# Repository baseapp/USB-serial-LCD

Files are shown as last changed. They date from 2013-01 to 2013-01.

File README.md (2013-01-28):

BaseApp USB-serial LCD/Keypad
-----------------------------

Supports HD44780 compatible LCDs(in 4-bit mode). Enumerates as a serial com port, and can be
used with software like LCD smartie for windows, or LCDproc etc. for
linux using matrixorbital commands. Also supports upto 4x4 matrix keypad.

List of supported matrix orbital commands supported is in MatrixOrbital.h

Code is based on http://dangerousprototypes.com/docs/USB_Universal_LCD_backpack

- This code is for PIC18F25K50, and can me modified easily for 18f45k50,
  both do not require external crystal for USB.
- No bootloader
- Keypad press/release output on serial

- Compiler - tested with mplabc18 v3.44
- Requires USB stack from microchip applications library

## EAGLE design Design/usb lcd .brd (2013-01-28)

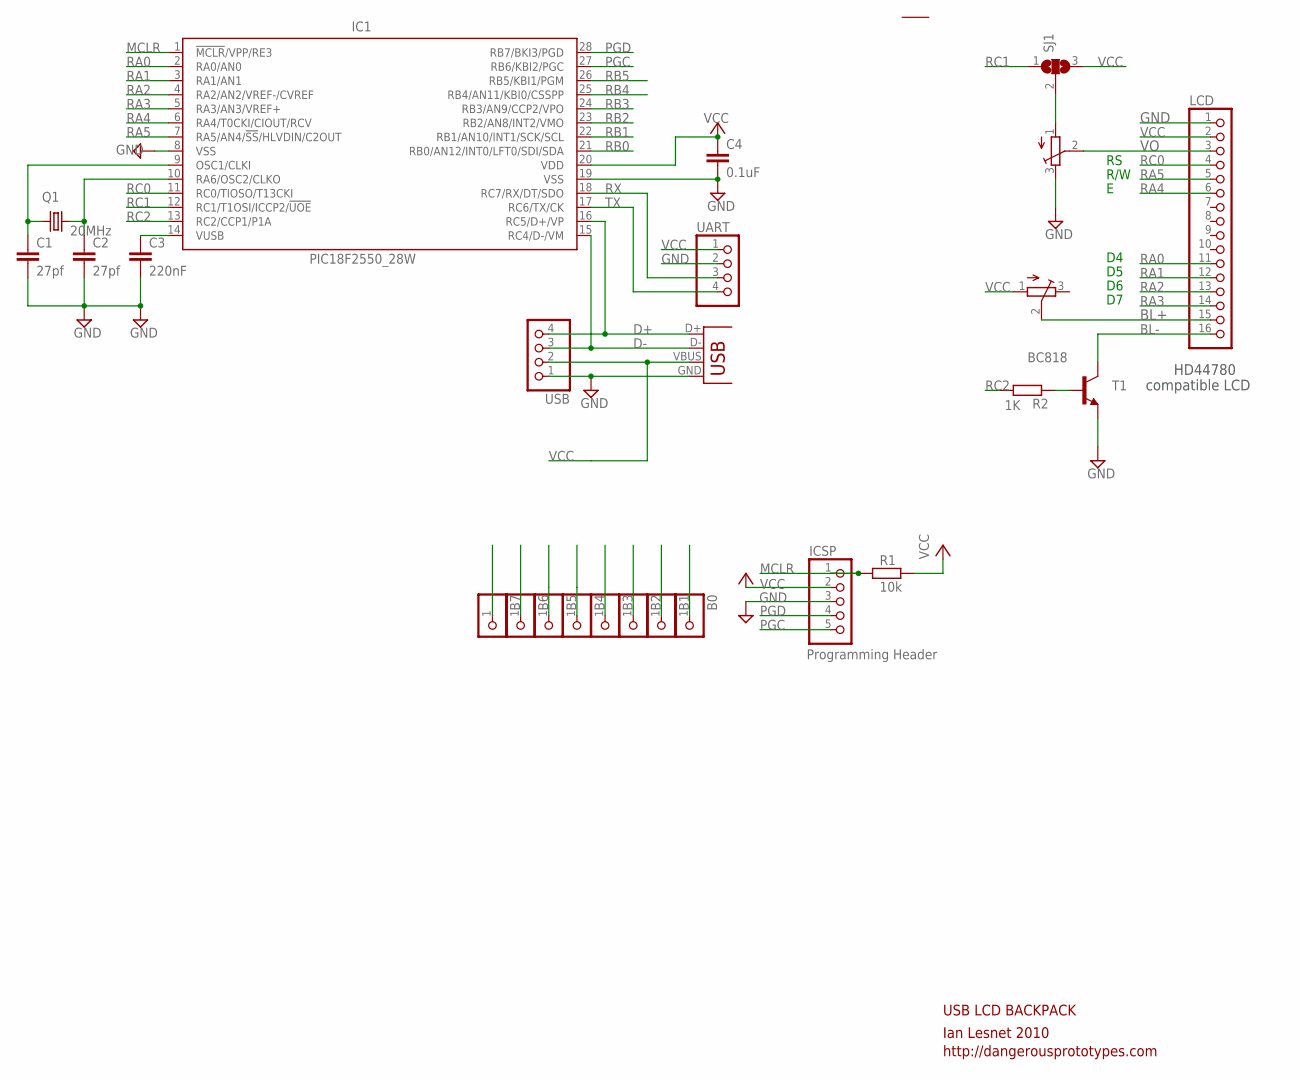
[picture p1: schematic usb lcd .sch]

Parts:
B0, B1, B2, B3, B4, B5, B6, B7: PINHD-1X1; 1X01
C1, C2: 27pf; C0805
C3: 220nF; C0805
C4: 0.1uF; C0805
IC1: PIC18F2550_28W; SO28W
ICSP: PINHD-1X5; 1X05
J1: USBSMD; USB-MINIB
LCD: PINHD-1X16; 1X16
Q1: 20MHz; HC49UP
R1: 10k; R0805
R2: 1K; M0805
SJ1: SJ2W; SJ_2
T1: BC818; SOT23-BEC
U$3, U$4: 3MM_TRIMPOT
UART: PINHD-1X4; 1X04
USB: PINHD-1X4; 1X04

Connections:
BASE: R2.1, T1.B
BL+: LCD.15, U$4.2 (S)
BL-: LCD.16, T1.C
D+: IC1.16 (RC5/D+/VP), J1.D+, USB.4
D-: IC1.15 (RC4/D-/VM), J1.D-, USB.3
GND: C1.2, C2.2, C3.2, C4.2, IC1.8 (VSS), IC1.19 (VSS), ICSP.3, J1.GND, LCD.1, T1.E, U$3.3 (E), UART.2, USB.1
MCLR: IC1.1 (!MCLR!/VPP/RE3), ICSP.1, R1.1
unnamed: SJ1.2, U$3.1 (A)
unnamed: C2.1, IC1.10 (RA6/OSC2/CLKO), Q1.2
unnamed: C1.1, IC1.9 (OSC1/CLKI), Q1.1
unnamed: C3.1, IC1.14 (VUSB)
PGC: B6.1, IC1.27 (RB6/KBI2/PGC), ICSP.5
PGD: B7.1, IC1.28 (RB7/BKI3/PGD), ICSP.4
RA0: IC1.2 (RA0/AN0), LCD.11
RA1: IC1.3 (RA1/AN1), LCD.12
RA2: IC1.4 (RA2/AN2/VREF-/CVREF), LCD.13
RA3: IC1.5 (RA3/AN3/VREF+), LCD.14
RA4: IC1.6 (RA4/T0CKI/CIOUT/RCV), LCD.6
RA5: IC1.7 (RA5/AN4/!SS!/HLVDIN/C2OUT), LCD.5
RB0: B0.1, IC1.21 (RB0/AN12/INT0/LFT0/SDI/SDA)
RB1: B1.1, IC1.22 (RB1/AN10/INT1/SCK/SCL)
RB2: B2.1, IC1.23 (RB2/AN8/INT2/VMO)
RB3: B3.1, IC1.24 (RB3/AN9/CCP2/VPO)
RB4: B4.1, IC1.25 (RB4/AN11/KBI0/CSSPP)
RB5: B5.1, IC1.26 (RB5/KBI1/PGM)
RC0: IC1.11 (RC0/TIOSO/T13CKI), LCD.4
RC1: IC1.12 (RC1/T1OSI/ICCP2/!UOE), SJ1.1
RC2: IC1.13 (RC2/CCP1/P1A), R2.2
RX: IC1.18 (RC7/RX/DT/SDO), UART.3
TX: IC1.17 (RC6/TX/CK), UART.4
VCC: C4.1, IC1.20 (VDD), ICSP.2, J1.VBUS, LCD.2, R1.2, SJ1.3, U$4.1 (A), UART.1, USB.2
VO: LCD.3, U$3.2 (S)

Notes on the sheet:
USB LCD BACKPACK
Ian Lesnet 2010
http://dangerousprototypes.com
HD44780
compatible LCD
R/W
Programming Header

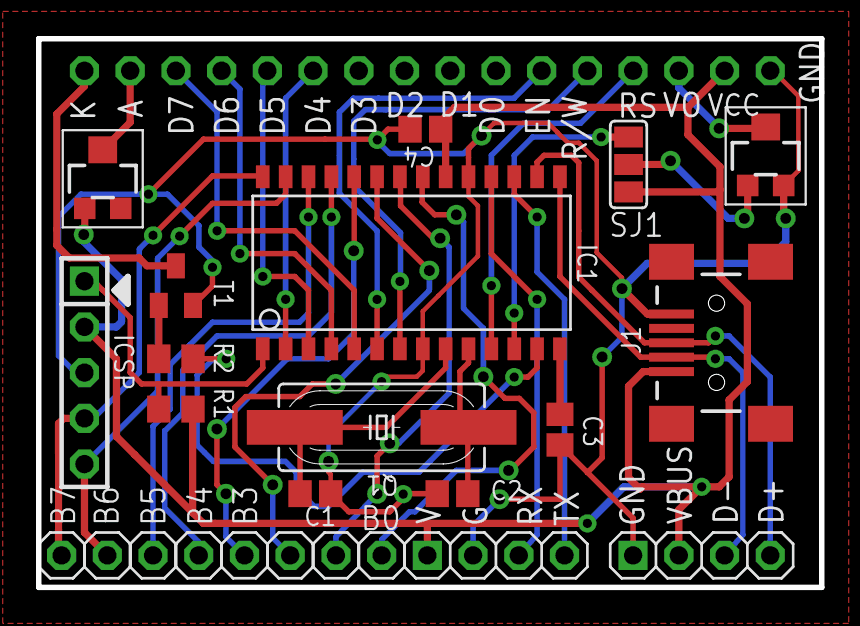
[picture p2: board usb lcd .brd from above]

Board: 2 copper layers, 43.5 x 30.5 mm, 25 parts (1 on the bottom side), 32 nets.

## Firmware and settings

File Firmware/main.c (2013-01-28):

//Due to licensing issues, we can't redistribute the Microchip USB source. 
//You can get it from the Microchip website for free: 
//http://www.microchip.com/usb
//
//1.Download and install the USB source. These files install to c:\Microchip Soultions\ by default.
//2.Place the project folder in the Microchip source install directory (c:\Microchip Soultions\ by default)
//3.Copy usb_config.h & usb_descriptors.c from \Microchip Solutions\USB Device - CDC - Basic Demo\CDC - Basic Demo - Firmware3\ to the project folder.
//4. That's it. You've got the latest source and we're compliant with the license.
//
//Depending on the install location you may need to tweak the include paths under Project->build options.
#include "globals.h"
#include "config.h"
#include "MatrixOrbital.h"
#include "keypad.h"

//this struct buffers the USB input because the stack doesn't like 1 byte reads
#pragma udata
static struct _usbbuffer{
	unsigned char inbuf[64];
	unsigned char cnt;
	unsigned char rdptr;
} ubuf;

//USB output buffer
#define USB_OUT_BUF 64
unsigned char buf[USB_OUT_BUF];
unsigned char uartincnt=0;

char stringBuffer[40];

static void init(void);
void usbbufservice(void);
void usbbufflush(void);
unsigned char usbbufgetbyte(unsigned char* c);
unsigned char waitforbyte(void);
unsigned char checkforbyte(void);
void sendok(void);
void send(unsigned char c);

#pragma code
void main(void)
{  
    unsigned char i,cmd, param[9];

    init();			//setup the crystal, pins, usb

    HD44780_Reset();//setup the LCD
    HD44780_Init();
    LCD_Home();
    LCD_Clear();
    LCD_Backlight(0);

    usbbufflush();	//setup the USB byte buffer

    delayMS(10);

    keypad_read_state();
    
    while(1)
    {
        USBDeviceTasks();

        if((USBDeviceState < CONFIGURED_STATE)||(USBSuspendControl==1))
            continue;
        usbbufservice();//load any USB data into byte buffer

        cmd=waitforbyte();//wait for a byte from USB

        if(cmd!=MATRIX_ORBITAL_COMMAND)
        {//assume text, if 254 then enter command mode

            LCD_WriteChar(cmd); //not a command, just write it to the display

        }else
        {//previous byte was 254, now get actual command
            switch(waitforbyte())
            {
                //switch on the command
                case BACKLIGHT_ON: //1 parameter (minutes 00=forever)
                    param[0]=waitforbyte();
                    LCD_Backlight(1);//turn it on, we ignore the parameter
                    break;
                case BACKLIGHT_OFF:
                    LCD_Backlight(0);//backlight off
                    break;
                case CLEAR:
                    LCD_Clear();
                    break;
                case HOME:
                    LCD_Home();
                    break;
                case POSITION: //2 parameters (col, row)
                    param[0]=waitforbyte();
                    param[1]=waitforbyte();
                    cmd=( ((param[1]-1)*20) + param[0] ); //convert to 20x4 layout (used defined lines, add rows...)
                    LCD_CursorPosition(cmd);
                    break;
                case UNDERLINE_CURSER_ON:
                    LCD_UnderlineCursor(1);
                    break;
                case UNDERLINE_CURSER_OFF:
                    LCD_UnderlineCursor(0);
                    break;
                case BLOCK_CURSER_ON:
                    LCD_BlinkCursor(1);
                    break;
                case BLOCK_CURSER_OFF:
                    LCD_BlinkCursor(0);
                    break;
                case BACKLIGHT_BRIGHTNESS_SET://1 parameter (brightness)
                case BACKLIGHT_BRIGHTNESS_SET_SAVE:
                    param[0]=waitforbyte();
                    LCD_Backlight(param[0]);
                    break;
                case CONTRAST_SET://1 parameter (brightness)
                case CONTRAST_SET_AND_SAVE:
                    param[0]=waitforbyte();
                    LCD_Contrast(param[0]);
                    break;
                case CUSTOM_CHARACTER: //9 parameters (character #, 8 byte bitmap)
                    LCD_WriteCGRAM(waitforbyte());//write character address
                    for(i=1; i<9; i++)
                    {
                        LCD_WriteRAM(waitforbyte()); //send 8 bitmap bytes
                    }
                    break;
                default: //error
                    break;
            }
        }
        CDCTxService();
    }
}//end main

void send(unsigned char c)
{
	unsigned char b[2];

  	if( mUSBUSARTIsTxTrfReady() ){ //it's always ready, but this could be done better
		b[0]=c;
		putUnsignedCharArrayUsbUsart(b,1);
	}	

}

void sendok(void)
{
	unsigned char b[2];

  	if( mUSBUSARTIsTxTrfReady() ){ //it's always ready, but this could be done better
		b[0]='1';//answer OK
		putUnsignedCharArrayUsbUsart(b,1);
	}	

}

unsigned char waitforbyte(void)
{
	unsigned char inbuf,togglebit=0;

        unsigned char temp;//calculate row number
        char output;
        char i; //loop var
        int len;// for  stringBuffer

	if(usbbufgetbyte(&inbuf)) return inbuf; //return data
	//wait for more USB data
	//services USB peripheral
	while(1)
        {            
            keypad_read_state();

            /* DO keypad stuff*/
            len=0;
            stringBuffer[0]=0x00;
            for(i=0;i<4;i++)
            {
                if((pressed_keys[i])!=0x0)
                {
                    temp=0;
                    while(pressed_keys[i]>>=1)
                        temp++;
                    output = keymap[i][temp]-'a'+'A';
                    stringBuffer[len]=output;len++;
                }
               
                if((released_keys[i])!=0x0)
                {
                    temp=0;
                    while(released_keys[i]>>=1)
                        temp++;
                    output = keymap[i][temp];
                    stringBuffer[len]=output;len++;
                }                
            }
            stringBuffer[len]=0x00;
            if(stringBuffer[0])
                putsUSBUSART(stringBuffer);

            USBDeviceTasks();
            if((USBDeviceState < CONFIGURED_STATE)||(USBSuspendControl==1))
            {
                    return 0; //goto USB_loop_jump; //USB gone, fail out to main loop
            }
            usbbufservice();//load any USB data into byte buffer
            if(usbbufgetbyte(&inbuf))
                return inbuf; //wait for more data
	    CDCTxService();
	}

} 

unsigned char checkforbyte(void)
{
	unsigned char inbuf;

	if(usbbufgetbyte(&inbuf)) return 1; //return data
	//wait for more USB data
	//services USB peripheral
	USBDeviceTasks(); 
   	if((USBDeviceState < CONFIGURED_STATE)||(USBSuspendControl==1)){
		return 1; //goto USB_loop_jump; //USB gone, fail out to main loop
	}
	usbbufservice();//load any USB data into byte buffer
	if(usbbufgetbyte(&inbuf)) return 1; //wait for more data
    CDCTxService();
	return 0;
} 

static void init(void)
{
	unsigned int cnt = 2048;
	
	//all pins digital
	//disable some defaults
        ADCON0bits.ADON=0;
        ADCON1 |= 0b1111;   	//all pins digital
	//CVRCON=0b00000000;

	//make sure everything is input (should be on startup, but just in case)
	TRISA=0xff;
        TRISB=0xff;
        TRISC=~0b0000111; //RC2 is pwm output, so TRIS=0,ANSEL=0, tris cleared later

        LCD_BL=0;//backlight off

        //pwm config for LCD_BL and LCD_VO
        PR2 = 63;//period
        CCP1CONbits.CCP1M=0b1111;//configure ccp module for pwm
        CCP2CONbits.CCP2M=0b1111;//configure ccp module for pwm
        //duty cycle is (CCPR1L:DC1B)/(4*(PR2+1))
        CCPR1L=0xff;
        CCPR2L=0xff;
        CCP1CONbits.DC1B=0x3;
        CCP1CONbits.DC1B=0x3;
        //start 8 bit timer2
        PIR1bits.TMR1IF=0;
        PIR2bits.TMR3IF=0;
        T2CONbits.T2CKPS=1;
        T2CONbits.TMR2ON=1;
        while(!PIR1bits.TMR2IF);
        TRISCbits.RC2=0;
        TRISCbits.RC1=0;
	
        OSCCONbits.IRCF0=1;
        OSCCONbits.IRCF1=1;
        OSCCONbits.IRCF2=1;

//        #if(USB_SPEED_OPTION == USB_FULL_SPEED)
            OSCTUNE = 0x80; //3X PLL ratio mode selected
            OSCCON = 0x70;  //Switch to 16MHz HFINTOSC
            OSCCON2 = 0x10; //Enable PLL, SOSC, PRI OSC drivers turned off

            ACTCONbits.ACTEN=0;
            ACTCONbits.ACTSRC=1;
            ACTCONbits.ACTEN=1;
            ACTCONbits.ACTUD=0;
//            *((unsigned char*)0xFB5) = 0x90;  //Enable active clock tuning for USB operation
//        #endif
        //Configure all I/O pins for digital mode (except RA0/AN0 which has POT on demo board)
        ANSELA = 0x00;
        ANSELB = 0xFF;
        ANSELC = 0x00;
        
        while(OSCCON2bits.PLLRDY != 1);   //Wait for PLL lock
//        while(ACTCONbits.ACTLOCK != 1);

        keypad_init();

        USBDeviceInit();
}

void usbbufservice(void)
{
	if(ubuf.cnt==0){//if the buffer is empty, get more data
		ubuf.cnt = getsUSBUSART(ubuf.inbuf,64);
		ubuf.rdptr=0;
	}
}

//puts a byte from the buffer in the byte, returns 1 if byte
unsigned char usbbufgetbyte(unsigned char* c)
{
	if(ubuf.cnt>0){
		*c=ubuf.inbuf[ubuf.rdptr];
		ubuf.cnt--;
		ubuf.rdptr++;
		return 1;
	}
	return 0;
}

void usbbufflush(void)
{
	ubuf.cnt = 0;
	ubuf.rdptr=0;
}

//
//
//the stack calls these, if they aren't here we get errors. 
//
//
void USBCBSuspend(void){}
void USBCBWakeFromSuspend(void){}
void USBCB_SOF_Handler(void){}
void USBCBErrorHandler(void){}
void USBCBCheckOtherReq(void){USBCheckCDCRequest();}//end
void USBCBStdSetDscHandler(void){}//end
void USBCBInitEP(void){CDCInitEP();}
BOOL USER_USB_CALLBACK_EVENT_HANDLER(USB_EVENT event, void *pdata, WORD size)
{
    switch(event){
        case EVENT_CONFIGURED: 
            USBCBInitEP();
            break;
        case EVENT_SET_DESCRIPTOR:
            USBCBStdSetDscHandler();
            break;
        case EVENT_EP0_REQUEST:
            USBCBCheckOtherReq();
            break;
        case EVENT_SOF:
            USBCB_SOF_Handler();
            break;
        case EVENT_SUSPEND:
            USBCBSuspend();
            break;
        case EVENT_RESUME:
            USBCBWakeFromSuspend();
            break;
        case EVENT_BUS_ERROR:
            USBCBErrorHandler();
            break;
        case EVENT_TRANSFER:
            Nop();
            break;
        default:
            break;
    }      
    return TRUE; 
}

/*      TODO remove all remaps        */

//#define REMAPPED_RESET_VECTOR_ADDRESS			0x800
//#define REMAPPED_HIGH_INTERRUPT_VECTOR_ADDRESS	0x808
//#define REMAPPED_LOW_INTERRUPT_VECTOR_ADDRESS	0x818

#define REMAPPED_RESET_VECTOR_ADDRESS			0x00
#define REMAPPED_HIGH_INTERRUPT_VECTOR_ADDRESS	0x08
#define REMAPPED_LOW_INTERRUPT_VECTOR_ADDRESS	0x18

//We didn't use the low priority interrupts, 
// but you could add your own code here
#pragma interruptlow InterruptHandlerLow
void InterruptHandlerLow(void){}

//We didn't use the low priority interrupts, 
// but you could add your own code here
#pragma interrupt InterruptHandlerHigh
void InterruptHandlerHigh(void){}

////these statements remap the vector to our function
////When the interrupt fires the PIC checks here for directions
//#pragma code REMAPPED_HIGH_INTERRUPT_VECTOR = REMAPPED_HIGH_INTERRUPT_VECTOR_ADDRESS
//void Remapped_High_ISR (void){
//     _asm goto InterruptHandlerHigh _endasm
//}
//
//#pragma code REMAPPED_LOW_INTERRUPT_VECTOR = REMAPPED_LOW_INTERRUPT_VECTOR_ADDRESS
//void Remapped_Low_ISR (void){
//     _asm goto InterruptHandlerLow _endasm
//}
//
////relocate the reset vector
//extern void _startup (void);
//#pragma code REMAPPED_RESET_VECTOR = REMAPPED_RESET_VECTOR_ADDRESS
//void _reset (void){
//    _asm goto _startup _endasm
//}
////set the initial vectors so this works without the bootloader too.
//#pragma code HIGH_INTERRUPT_VECTOR = 0x08
//void High_ISR (void){
//     _asm goto REMAPPED_HIGH_INTERRUPT_VECTOR_ADDRESS _endasm
//}
//#pragma code LOW_INTERRUPT_VECTOR = 0x18
//void Low_ISR (void){
//     _asm goto REMAPPED_LOW_INTERRUPT_VECTOR_ADDRESS _endasm
//}
//

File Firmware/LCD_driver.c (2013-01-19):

//********************************************************************
//
//			Color LCD (128x128) Basic Library
//             (Written for ARM LPC2148)
//
//    					3-9-2008
//			Copyright Spark Fun Electronics© 2008
//						Ryan Owens
//					ryan at sparkfun.com
//
//		See LCD_driver.h for I/O pin and register definitions
//			*Delays assume a 16MHz external clock
//				(should be adjusted accordingly)
//
//
//		Reference: Jim Lynch's "Nokia 6100 LCD Display Driver"
//(http://www.sparkfun.com/tutorial/Nokia%206100%20LCD%20Display%20Driver.pdf)
//	
//		Special thanks to Rich for the heads up on the new driver and
//			for pointing us in the right direction on the
//						initialization code.
//********************************************************************
#include "Compiler.h"
#include "LCD_driver.h"
#include "HardwareProfile.h"
//******************************************************
//
//			General Function Definitions
//
//******************************************************
#define LCD_SCK		LAT_SCK	
#define LCD_DIO		LAT_MOSI	 
#define LCD_RES 	LAT_RESET
#define LCD_CS		LAT_CS

#define LCD_SCK_DIR		TRIS_SCK			
#define LCD_DIO_DIR		TRIS_MOSI			 
#define LCD_RES_DIR 	TRIS_RESET
#define LCD_CS_DIR		TRIS_CS	

//Usage: LCD_command(DISPON);
//Inputs: char data - The command character to be sent to the LCD
//Outputs: None
//Description: This function sends a command signal and an 8 bit command
//				character to the LCD in a 9-bit package
void LCD_command(unsigned char data)
{
	char j;

	//DisableSPIPPS();

	LCD_SCK=0;    
	LCD_CS=0;      	// Enable Chip (Bring CS signal LOW)
 
   	LCD_DIO=0;     	// Prepare Data Line (Bring DIO signal LOW)

        LCD_SCK=0;      	// send clock pulse (Bring clock signal LOW)
        LCD_SCK=1;		// (Bring clock signal HIGH)
        LCD_SCK=0;    	// send clock pulse (Bring clock signal LOW)
	EnableSPIPPS();
	SSP2BUF=data;
	while(SSP2STATbits.BF==0);

/*
    for (j = 0; j < 8; j++)
    {
        if ((data & 0x80) == 0x80) LCD_DIO=1;	//Set data line HIGH
        else LCD_DIO=0;							//Set data line LOW

    	LCD_SCK=0;      	// send clock pulse (Bring clock signal LOW)
    	LCD_SCK=1;			// (Bring clock signal HIGH)

        data <<= 1;
    }
*/

    LCD_CS=1;    		// Disable Chip (Bring CS signal HIGH)
	DisableSPIPPS();

}

//Usage: LCD_data(0x03);
//Inputs: char data - The data character to be sent to the LCD
//Outputs: None
//Description: This function sends a data signal and an 8 bit data character
//				to the LCD in a 9-bit package
void LCD_data(unsigned char data)
{
	char j;

	LCD_SCK=0;     
	LCD_CS=0;      	// Enable Chip (Bring CS signal LOW)    

	LCD_DIO=1;    	// Prepare Data Line (Bring DIO signal HIGH!!!)

    LCD_SCK=0;    	// send clock pulse (Bring clock signal LOW)
    LCD_SCK=1;		// (Bring clock signal HIGH)
    LCD_SCK=0;    	// send clock pulse (Bring clock signal LOW)
	EnableSPIPPS();
	SSP2BUF=data;
	while(SSP2STATbits.BF==0);

/*	for (j = 0; j < 8; j++)
    {
        if ((data & 0x80) == 0x80) LCD_DIO=1;	//Set data line HIGH
        else LCD_DIO=0;							//Set data line LOW

        LCD_SCK=0;   							// send clock pulse (Bring clock signal LOW)
        LCD_SCK=1;								// (Bring clock signal HIGH)
  
      	data <<= 1;
    }*/

    LCD_CS=1;     		// Disable Chip (Bring CS signal HIGH)
	DisableSPIPPS();
}

//Usage: LCD_init();
//Inputs: None
//Outputs: None
//Description: This function will initialize the LCD, regardless of whether the
//				LCD contains the EPSON or PHILLIPS driver
void LCD_init(void)
{
    long j;
	
    // reset display
	LCD_SCK_DIR=0; //Assign LCD pins as Outputs
	LCD_DIO_DIR=0;			 
	LCD_RES_DIR=0; 	
	LCD_CS_DIR=0;	

// test
/*
   LCD_SCK=1;		
   LCD_DIO=1;					
   LCD_RES=1; 	
   LCD_CS=1;	
   LCD_RES=0; 	
   LCD_CS=0;	
*/ 
    LCD_SCK=0;						//output_low (SPI_CLK);
	LCD_DIO=0;						//output_low (SPI_DO);

    LCD_CS=1;				//output_high (LCD_CS);
    for (j = 0; j < 16; j++);
    LCD_RES=0;				//output_low (LCD_RESET);
    for (j = 0; j < 300000; j++);
    LCD_RES=1;				//output_high (LCD_RESET);
    LCD_SCK=1;
	LCD_DIO=1;
    for (j = 0; j < 300000; j++);	//delay_ms(100);


    LCD_command(DISCTL);  	// display control(EPSON)
    LCD_data(0x0c);   	//0xc (0x00) 12 = 1100 - CL dividing ratio [don't divide] switching period 8H (default)
    LCD_data(0x20);		//0c20
    LCD_data(0x02);		//0x02 (0x0a)	

    LCD_data(0x01);		//??
	
    LCD_command(COMSCN);  	// common scanning direction(EPSON)
    LCD_data(0x01);
    
    LCD_command(OSCON);  	// internal oscialltor ON(EPSON)
    
    LCD_command(SLPOUT);  	// sleep out(EPSON)
	LCD_command(SLEEPOUT);	//sleep out(PHILLIPS)

    LCD_command(PWRCTR); 	// power ctrl(EPSON)
    LCD_data(0x0F);    //everything on, no external reference resistors
    LCD_command(BSTRON);	//Booset On(PHILLIPS)
    
    LCD_command(DISINV);  	// invert display mode(EPSON)
	LCD_command(INVON);	// invert display mode(PHILLIPS)

    LCD_command(DATCTL);  	// data control(EPSON)
    LCD_data(0x03);	//bit2 adscan dir, bit1 col, bit0 page
    LCD_data(0x00);   	//0x00 normal RGB arrangement
    LCD_data(0x02);   	//0x01 8-bit grayscale

	LCD_command(MADCTL);	//Memory Access Control(PHILLIPS)
	LCD_data(0xC8);
	
	LCD_command(COLMOD);	//Set Color Mode(PHILLIPS)
	LCD_data(0x02);	


    LCD_command(VOLCTR);  	// electronic volume, this is the contrast/brightness(EPSON)
    LCD_data(0x24);   	// volume (contrast) setting - fine tuning, original
    LCD_data(0x03);   	// internal resistor ratio - coarse adjustment
	LCD_command(SETCON);	//Set Contrast(PHILLIPS)
	LCD_data(0x30);	
	/*
    LCD_command(TMPGRD);
	LCD_data(0x00);		// default
    

	LCD_command(PTLOUT);	// Partial Out (no partial display)    
*/
    LCD_command(NOP);  	// nop(EPSON)
	LCD_command(NOPP);		// nop(PHILLIPS)

    LCD_command(DISON);   	// display on(EPSON)
	LCD_command(DISPON);	// display on(PHILLIPS)
}

//  sets the starting page(row) and column (x & y) coordinates in ram,
//  then writes the colour to display memory.  The ending x & y are left
//  maxed out so one can continue sending colour data bytes to the 'open'
//  RAMWR command to fill further memory.  issuing any other command
//  finishes RAMWR.
void pset(unsigned int color, unsigned char x, unsigned char y)
{

	#ifdef EPSON
		LCD_command(PASET);   // page start/end ram
		LCD_data(x);
		//LCD_data(x);
		LCD_data(ENDPAGE);
  
		LCD_command(CASET);   // column start/end ram
		LCD_data(y);
		//LCD_data(y);
		LCD_data(ENDCOL);
  
		LCD_command(RAMWR);    // write
		//LCD_data(color);
		//LCDCommand(RAMWR);    // write
	//LCD_data(0b11110000);
	//LCD_data(0x00);
	//LCD_data(0x00);

		LCD_data((color>>4)&0x00FF);
		LCD_data((color&0x000F)<<4);
		LCD_data(0x00);  	// nop(EPSON)	
	#endif
}
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

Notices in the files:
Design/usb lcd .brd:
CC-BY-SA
